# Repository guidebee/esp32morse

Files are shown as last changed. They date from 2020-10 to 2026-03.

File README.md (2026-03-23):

# Morse Code LoRa Walkie-Talkie

Morse Code Walkie Talkie

A battery-powered Morse code walkie-talkie built on the **TTGO LoRa32 v1** (ESP32). Type messages in Morse code using a physical key, transmit over LoRa radio, and receive messages on an OLED display — with multi-device support, AES encryption, and configurable channels.

[Watch Demo on YouTube](https://www.youtube.com/watch?v=TG7tIteto1E)

---

## Hardware

- **Board**: TTGO LoRa32 v1 (ESP32 + SX127x LoRa + SSD1306 OLED)
- **Framework**: PlatformIO / Arduino (C++)
- **Pins**:
  - `GPIO 35` — Battery level ADC
  - `GPIO 33` — Power switch
  - `GPIO 12` — Receiver LED
  - `GPIO 13` — Bluetooth LED

---

## Features

- **Morse code input** via physical key — short press = dit (`.`), long press = dah (`-`)
- **LoRa radio** for long-range communication (up to several kilometers)
- **OLED display** split into: scrolling top screen (received messages), bottom screen (composing), top bar (uptime/title), status bar (device/signal info + battery indicator)
- **Device discovery** — auto-tracks nearby nodes by chip ID and assigns short indexes
- **AES encryption** for secure message transmission
- **Multi-channel support** — configurable channel ID and LoRa sync word
- **Buzzer feedback** — audible dit/dah tones, message sent/received sounds, error beeps
- **BLE toggle** — optional Bluetooth support
- **Battery level indicator** in the status bar corner
- **Deep sleep support** (optional, disabled by default)

---

## Controls

| Button | Action |
|---|---|
| **Main** (short press) | Dit (`.`) |
| **Main** (long press) | Dah (`-`) |
| **Left** | Backspace (delete last character) |
| **Right** | Insert space |
| **OK** | Send message (if composing), or enter Options menu (press 3× when idle) |

Max message length is 36 characters — long messages are auto-sent when the limit is reached.

---

## Options Menu

Press **OK** three times while idle to enter the settings menu. Navigate with Left/Right, confirm with OK.

| Option | Description |
|---|---|
| Device Name | Set a display name for this node |
| Play Sound | Toggle buzzer feedback on/off |
| Bluetooth | Enable/disable BLE |
| Channel Id | Set the channel number (numeric) |
| Sync Word | Set the LoRa sync word (0x00–0xFF) |
| Input Speed | Normal (150 ms threshold) or Fast (100 ms) |
| Exit | Return to main screen |

Settings are persisted to flash via the `Preferences` library.

---

## Build & Flash

### Requirements

- [PlatformIO](https://platformio.org/) (VS Code extension or CLI)

### Libraries (auto-installed via `platformio.ini`)

- `adafruit/Adafruit BusIO`
- `thijse/ArduinoLog`
- `arduinogetstarted/ezButton`
- `sandeepmistry/LoRa`
- `adafruit/Adafruit GFX Library`
- `adafruit/Adafruit SSD1306`

### Flash

Select the environment matching your OS:

```bash
# macOS
pio run -e ttgo-lora32-v1-mac -t upload

# Windows (default COM3)
pio run -e ttgo-lora32-v1-windows -t upload

# Linux
pio run -e ttgo-lora32-v1-unix -t upload
```

Adjust the `upload_port` in `platformio.ini` if your serial port differs.

---

## Message Protocol

Each LoRa packet includes the sender's chip ID and a message type:

| Type | Description |
|---|---|
| `HELLO` | Broadcast on startup; announces device name and enables discovery |
| `TEXT` | A Morse-decoded text message |
| `TEXT_ACK` | Acknowledgment of a received text message |

Received messages are displayed as `<index>:<device_name> <text>` in the top screen.

---

## Photos

| | |
|---|---|
|  |  |
|  |  |

---

## License

MIT

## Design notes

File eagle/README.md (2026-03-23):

# ESP32 Morse LoRa - PCB Design (Eagle)

PCB design for the LoRa Morse code walkie-talkie, designed in Autodesk EAGLE 9.6.2.

## Files

| File | Description |
|---|---|
| `morse_lora_v6.sch` | Latest schematic |
| `morse_lora_v6.brd` | Latest board layout |
| `morse_lora_v1–v5.*` | Prior revision history |

## Board Specs

- **Size**: ~55mm × 83mm (2.2" × 3.3")
- **Layers**: 2 (Top + Bottom)
- **Components**: 29 (through-hole / PTH)
- **Software**: EAGLE 9.6.2

## Bill of Materials (v6)

| Ref | Qty | Value | Description |
|-----|-----|---|---|
| ESP32LORA | 1 | — | TTGO WiFi-LoRa-32 v1 module |
| C1–C4 | 4 | 0.1µF 50V | Decoupling capacitors |
| R1–R6 | 6 | 10kΩ 1/4W | Button pull-up/pull-down resistors |
| R7–R9 | 3 | 330Ω 1/10W | LED current limiting resistors |
| D-REC | 1 | Red 5mm LED | Receive indicator |
| D-BUT | 1 | Red 5mm LED | Button press feedback |
| D-BLU | 1 | Blue 5mm LED | Radio/BT status |
| RIGHT, LEFT, OK | 3 | 6mm switch | Navigation buttons (momentary PTH) |
| MAIN | 1 | 12mm switch | Main/power button (momentary PTH) |
| SLEEP | 1 | EG1218 | Sleep mode toggle switch |
| BUZZER | 1 | — | PTH electromechanical buzzer |

## Viewing the Files

Since EAGLE `.brd`/`.sch` files are XML-based, you can view them with:

- **[Autodesk EAGLE](https://www.autodesk.com/products/eagle/)** (free tier available) — full editing
- **[KiCad](https://www.kicad.org/)** with the EAGLE import plugin — open source
- **[EasyEDA](https://easyeda.com/)** — browser-based, supports EAGLE import
- **[Gerber viewers](https://www.pcbway.com/project/OnlineGerberViewer.html)** — after exporting Gerbers from EAGLE

## Design Revision History

| Version | Notes |
|---|---|
| v1 | Initial design — PTH switches, 5mm LEDs, discrete passives |
| v2 | Minor iteration on v1 |
| v3 | SMD redesign (0603 resistors, 1206 LEDs, SMD buzzer) — later reverted |
| v4 | Reverted to PTH; added SLEEP switch |
| v5 | Minor iteration on v4 |
| v6 | Added 330Ω LED current-limiting resistors (R7–R9); upgraded MAIN to 12mm switch |

The v3 SMD attempt was reverted in v4, settling on a PTH-first approach for easier hand-assembly and mechanical reliability of the buttons/switches.

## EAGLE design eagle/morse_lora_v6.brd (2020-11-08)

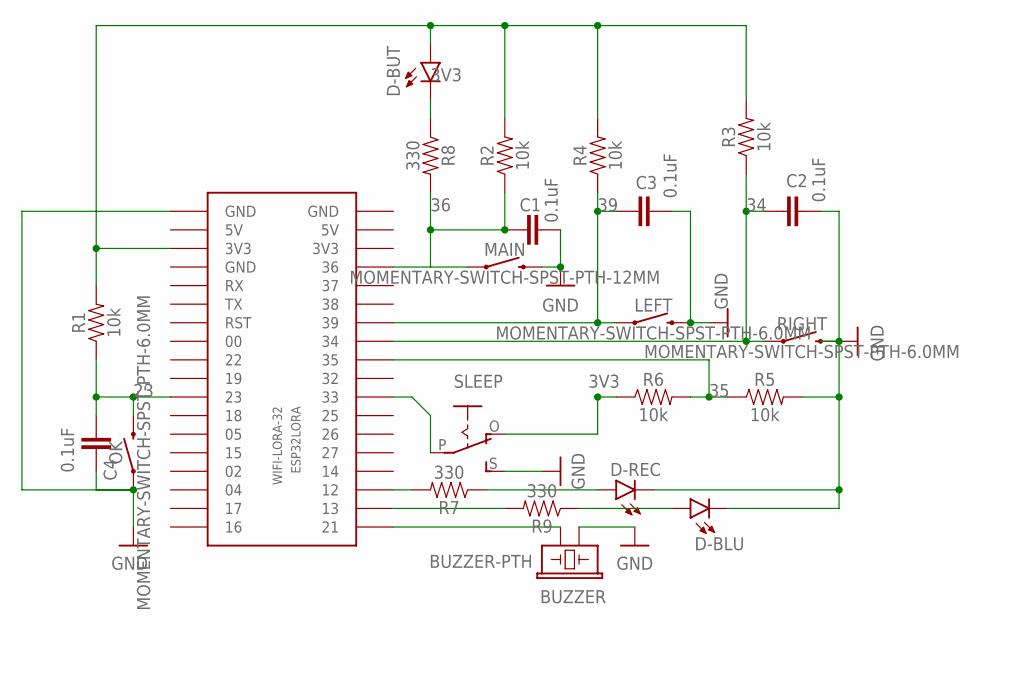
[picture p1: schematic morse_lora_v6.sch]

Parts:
BUZZER: BUZZER-PTH; BUZZER-12MM
C1, C2, C3, C4: 0.1uF; CAP-PTH-SMALL-KIT
D-BLU: LED5MM; LED_5MM
D-BUT: LED5MM; LED_5MM
D-REC: LED5MM; LED_5MM
ESP32LORA: WIFI-LORA-32; 2.54MM_2X18
LEFT: MOMENTARY-SWITCH-SPST-PTH-6.0MM; TACTILE_SWITCH_PTH_6.0MM
MAIN: MOMENTARY-SWITCH-SPST-PTH-12MM; TACTILE_SWITCH_PTH_12MM
OK: MOMENTARY-SWITCH-SPST-PTH-6.0MM; TACTILE_SWITCH_PTH_6.0MM
R1, R2, R3, R4, R5, R6: 10k; AXIAL-0.3-KIT
R7, R8, R9: 330; AXIAL-0.3
RIGHT: MOMENTARY-SWITCH-SPST-PTH-6.0MM; TACTILE_SWITCH_PTH_6.0MM
SLEEP: EG1218S; EG1218

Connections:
3V3: D-BUT.A, ESP32LORA.P$3 (3V3), R1.P$2 (2), R2.P$2 (2), R3.P$2 (2), R4.P$2 (2), R6.P$1 (1), SLEEP.O
23: C4.2, ESP32LORA.P$11 (23), OK.3 (2), R1.P$1 (1)
34: C2.2, ESP32LORA.P$29 (34), R3.P$1 (1), RIGHT.1
35: ESP32LORA.P$28 (35), R5.P$1 (1), R6.P$2 (2)
36: C1.2, ESP32LORA.P$33 (36), MAIN.1, R2.P$1 (1), R8.P$2 (2)
39: C3.1, ESP32LORA.P$30 (39), LEFT.1, R4.P$1 (1)
GND: BUZZER.- (2), C1.1, C2.1, C3.2, C4.1, D-BLU.K (C), D-REC.K (C), ESP32LORA.P$1 (GND), LEFT.3 (2), MAIN.3 (2), OK.1, R5.P$2 (2), RIGHT.3 (2), SLEEP.S
unnamed: ESP32LORA.P$21 (12), R7.P$2 (2)
unnamed: D-BUT.K (C), R8.P$1 (1)
unnamed: D-BLU.A, R9.P$1 (1)
unnamed: BUZZER.+ (1), ESP32LORA.P$19 (21)
unnamed: D-REC.A, R7.P$1 (1)
unnamed: ESP32LORA.P$20 (13), R9.P$2 (2)
unnamed: ESP32LORA.P$26 (33), SLEEP.P

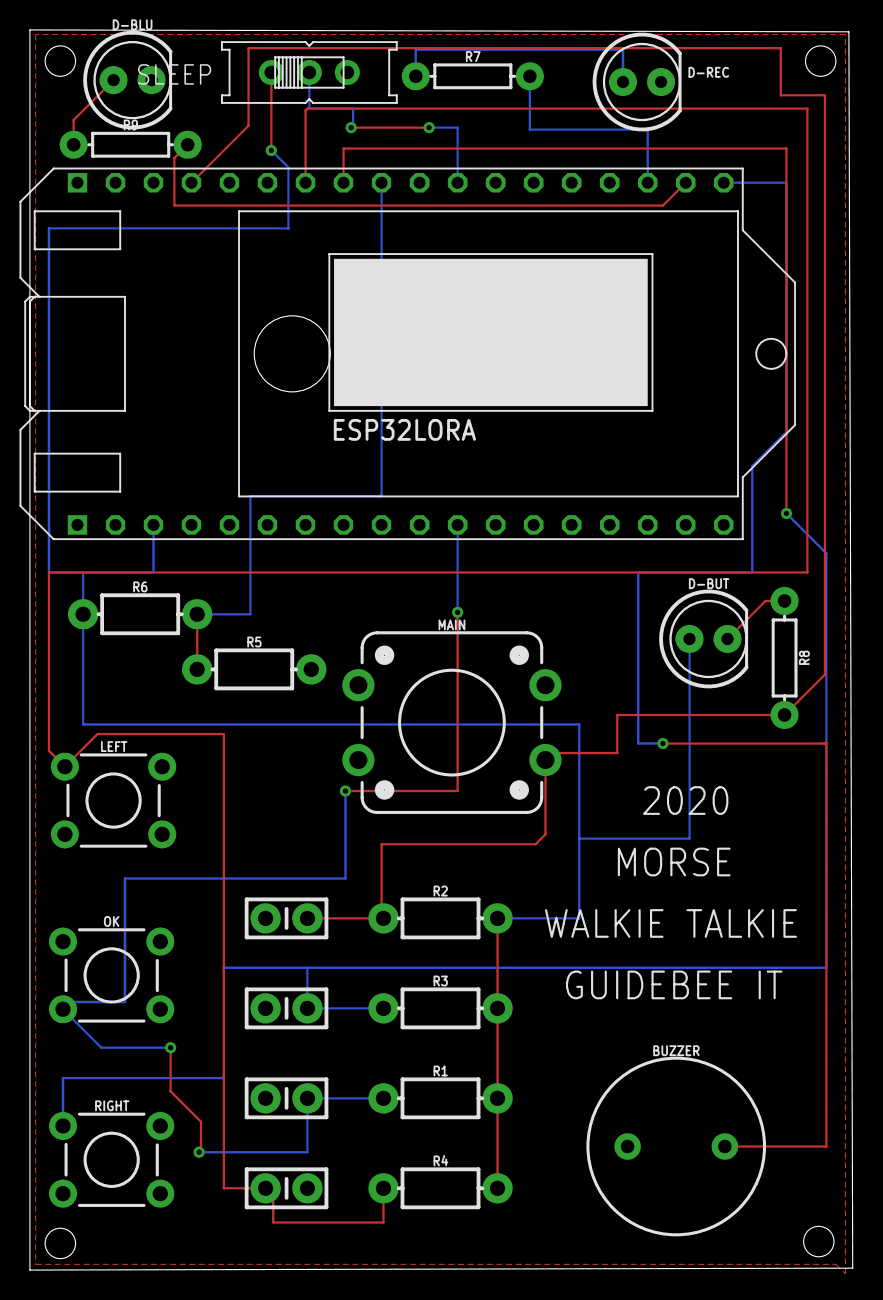
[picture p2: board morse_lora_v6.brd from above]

Board: 2 copper layers, 55.0 x 82.9 mm, 23 parts (0 on the bottom side), 14 nets.

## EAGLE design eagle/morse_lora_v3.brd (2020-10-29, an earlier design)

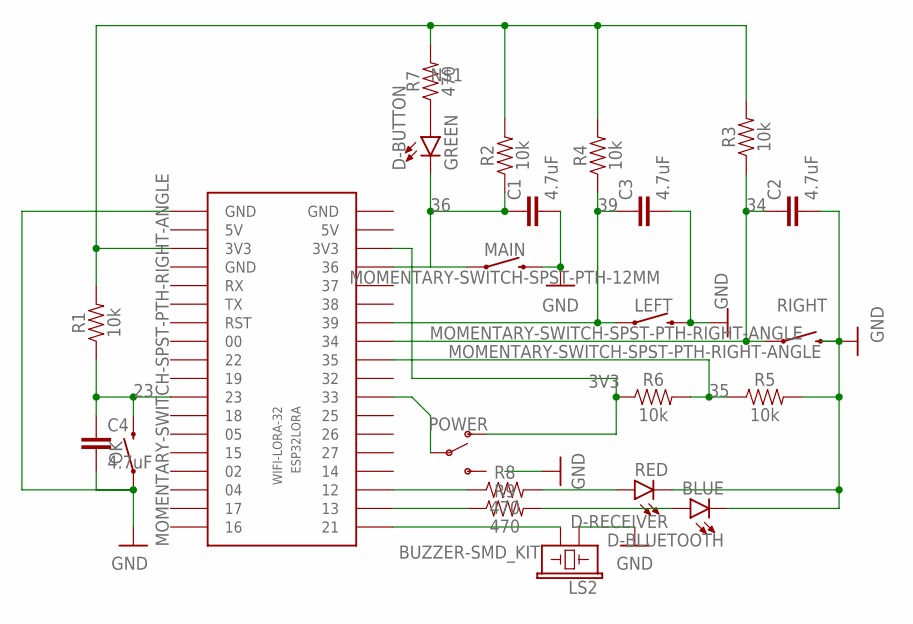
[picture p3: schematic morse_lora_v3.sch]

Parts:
C1, C2, C3, C4: 4.7uF; 0603
D-BLUETOOTH: BLUE; LED-1206
D-BUTTON: GREEN; LED-1206
D-RECEIVER: RED; LED-1206
ESP32LORA: WIFI-LORA-32; 2.54MM_2X18
LEFT: MOMENTARY-SWITCH-SPST-PTH-RIGHT-ANGLE; TACTILE_SWITCH_PTH_RIGHT_ANGLE
LS2: BUZZER-SMD_KIT; BUZZER-CCV-KIT
MAIN: MOMENTARY-SWITCH-SPST-PTH-12MM; TACTILE_SWITCH_PTH_12MM
OK: MOMENTARY-SWITCH-SPST-PTH-RIGHT-ANGLE; TACTILE_SWITCH_PTH_RIGHT_ANGLE
POWER: SWITCH-SPDT-SMD-RIGHT-ANGLE; SWITCH_SPST_SMD_A
R1, R2, R3, R4, R5, R6: 10k; 0603
R7, R8, R9: 470; 0603
RIGHT: MOMENTARY-SWITCH-SPST-PTH-RIGHT-ANGLE; TACTILE_SWITCH_PTH_RIGHT_ANGLE

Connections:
3V3: ESP32LORA.P$3 (3V3), ESP32LORA.P$34 (3V3), POWER.1 (O), R1.2, R2.2, R3.2, R4.2, R6.1, R7.2
23: C4.1, ESP32LORA.P$11 (23), OK.2, R1.1
34: C2.1, ESP32LORA.P$29 (34), R3.1, RIGHT.1
35: ESP32LORA.P$28 (35), R5.1, R6.2
36: C1.1, D-BUTTON.C, ESP32LORA.P$33 (36), MAIN.1, R2.1
39: C3.1, ESP32LORA.P$30 (39), LEFT.1, R4.1
GND: C1.2, C2.2, C3.2, C4.2, D-BLUETOOTH.C, D-RECEIVER.C, ESP32LORA.P$1 (GND), LEFT.2, LS2.+ (1), MAIN.3 (2), OK.1, R5.2, RIGHT.2
unnamed: D-BUTTON.A, R7.1
unnamed: D-RECEIVER.A, R8.2
unnamed: ESP32LORA.P$20 (13), R9.1
unnamed: ESP32LORA.P$19 (21), LS2.- (2)
unnamed: ESP32LORA.P$21 (12), R8.1
unnamed: D-BLUETOOTH.A, R9.2
unnamed: ESP32LORA.P$26 (33), POWER.2

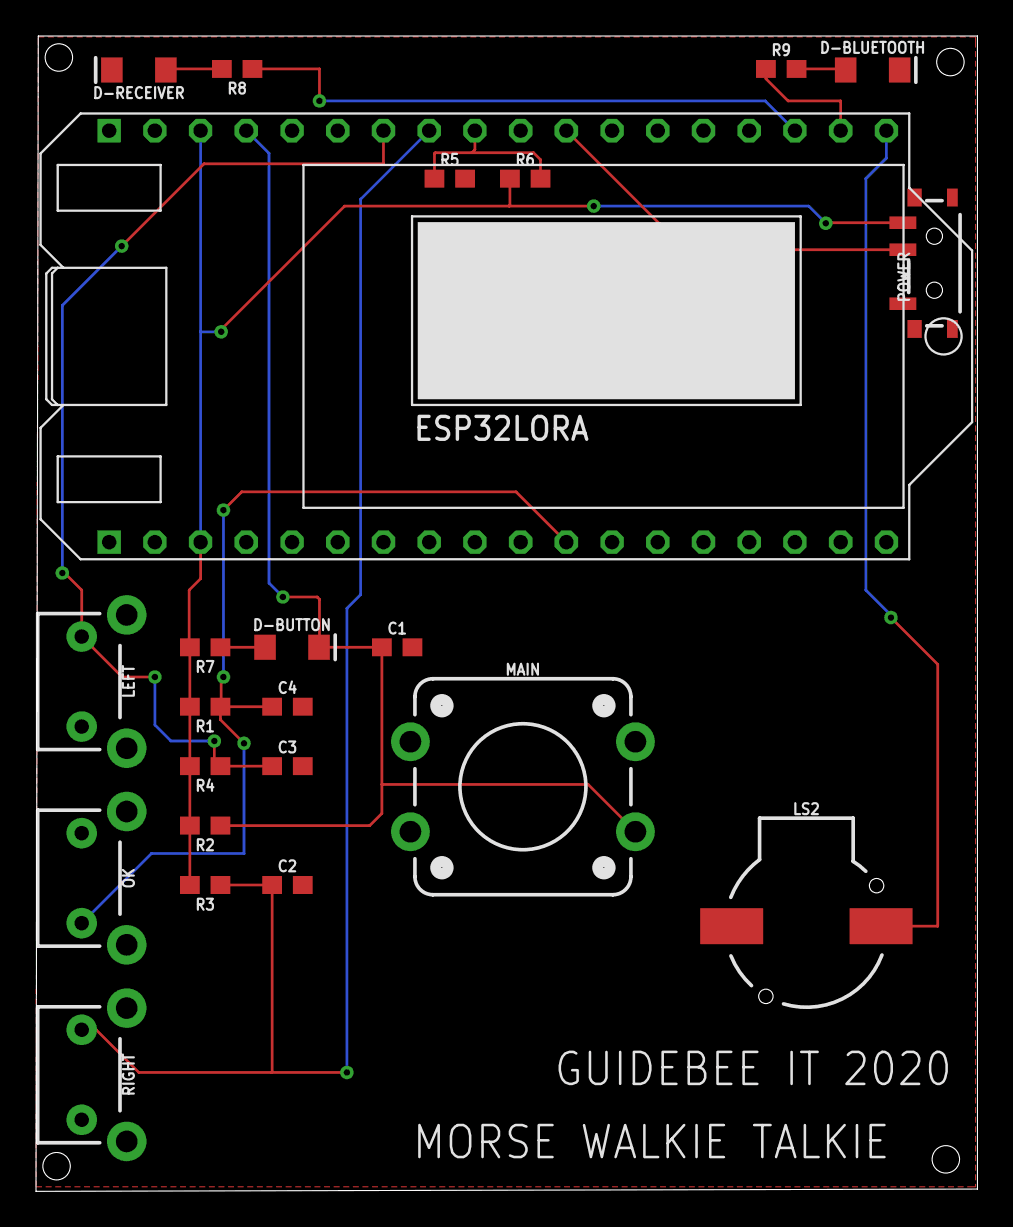
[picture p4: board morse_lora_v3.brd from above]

Board: 2 copper layers, 52.3 x 64.2 mm, 23 parts (0 on the bottom side), 14 nets.

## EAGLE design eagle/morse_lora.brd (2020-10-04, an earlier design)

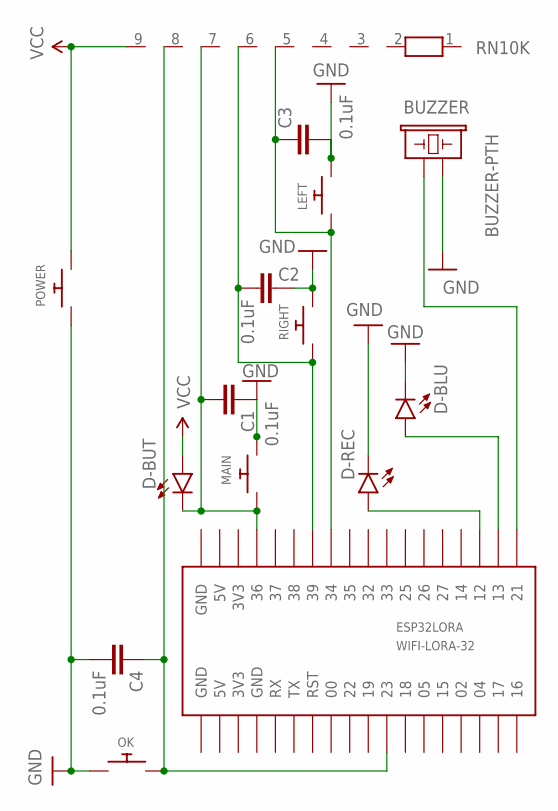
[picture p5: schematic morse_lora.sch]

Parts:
BUZZER: BUZZER-PTH; BUZZER-12MM
C1, C2, C3, C4: 0.1uF; CAP-PTH-SMALL-KIT
D-BLU: LED5MM; LED_5MM
D-BUT: LED5MM; LED_5MM
D-REC: LED5MM; LED_5MM
ESP32LORA: WIFI-LORA-32; 2.54MM_2X18
LEFT: SWITCH_PUSHBUTTONEVQ-PE; TACT_PANA-EVQ
MAIN: SWITCH_PUSHBUTTONEVQ-PE; TACT_PANA-EVQ
OK: SWITCH_PUSHBUTTONEVQ-PE; TACT_PANA-EVQ
POWER: SWITCH_PUSHBUTTONEVQ-PE; TACT_PANA-EVQ
RIGHT: SWITCH_PUSHBUTTONEVQ-PE; TACT_PANA-EVQ
RN10K: RN08; RN-9

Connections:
GND: BUZZER.- (2), C1.1, C2.1, C3.2, C4.2, D-BLU.K (C), D-REC.K (C), LEFT.P$2, MAIN.P$2, OK.P$1, POWER.P$1, RIGHT.P$2
unnamed: C1.2, D-BUT.K (C), ESP32LORA.P$33 (36), MAIN.P$1, RN10K.7
unnamed: C2.2, ESP32LORA.P$30 (39), RIGHT.P$1, RN10K.6
unnamed: C3.1, ESP32LORA.P$29 (34), LEFT.P$1, RN10K.5
unnamed: BUZZER.+ (1), ESP32LORA.P$19 (21)
unnamed: D-REC.A, ESP32LORA.P$21 (12)
unnamed: D-BLU.A, ESP32LORA.P$20 (13)
unnamed: C4.1, ESP32LORA.P$11 (23), OK.P$2, RN10K.8
VCC: D-BUT.A, POWER.P$2, RN10K.9

Board: 2 copper layers, 15 parts (0 on the bottom side), 9 nets, no tracks yet.

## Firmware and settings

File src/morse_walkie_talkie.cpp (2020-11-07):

//
// Created by Jing SHEN on 27/9/20.
//
#include <string>
#include "morse_walkie_talkie.hpp"
#include <soc/efuse_reg.h>
#include "configuration.hpp"

#define BATTERY_LEVEL_PIN 35
#define MAX_MESSAGE_LENGTH 36
#define POWER_SWITCH_PIN 33
#define BUTTON_PIN_BITMASK 0x200000000 // 2^33 in hex

bool isOptionMode = false;
Configuration globalConfiguration;
union {
    uint32_t parts[4];
    unsigned char bytes[16];
} encryptedChipId;

void MorseWalkieTalkie::sendMessage(char character) {
    if (!message.empty()) {
        lastChar = ' ';
        loRaRadio.sendMessage(message);
        bottomScreen.print(character);
        auto morseText = morseCode.generateDitDashString(message);
        Serial.print(morseText.c_str());
        if (globalConfiguration.playSound) {
            buzzer.playMessageSent();
        }
        receiverLed.signalMessageSent();
        message = "";
    }
}


void MorseWalkieTalkie::deleteLastKey() {
    bool deleted = bottomScreen.backspace();
    if (deleted) {
        message = message.substr(0, message.length() - 1);
    }
}


void MorseWalkieTalkie::onEmit(char character, std::string raw) {

    switch (character) {
        case '*':
            deleteLastKey();
            break;
        case '^':
            if (globalConfiguration.playSound) {
                buzzer.playError();
            }
            receiverLed.signalError();
            break;
        default:
            if (!(character == ' ' and lastChar == ' ')) {
                if (character != '\n') {
                    message += character;
                    bottomScreen.print(character);
                    receiverLed.signalMorse(raw);
                }
            }
            lastChar = character;
            if (character == '\n') {
                sendMessage(character);
            }
            if (message.length() >= MAX_MESSAGE_LENGTH) {
                sendMessage('-');
            }
            break;
    }

}

void MorseWalkieTalkie::onCharStart() {

}

void MorseWalkieTalkie::onCharEnd(char dotOrDash, int length) {
    if (globalConfiguration.playSound) {
        if (dotOrDash == '.') {
            buzzer.playDi();
        } else if (dotOrDash == '-') {
            buzzer.playDah();
        }
    }
}


void MorseWalkieTalkie::onMainPressed() {
    last_mills = millis();

    isDown = true;

    morseCode.setOnOff(true);
}


void MorseWalkieTalkie::saveConfiguration() {
    preferences.begin("guidebeeit", false);
    preferences.putString("deviceName", "Harry");
    preferences.putString("channelId", "<1234>");
    preferences.putBool("inputSpeed", false);
    preferences.putUChar("syncWord", 0x34);
    preferences.putBool("playSound", true);
    preferences.end();
}


void MorseWalkieTalkie::readConfiguration() {
    uint64_t chipId = ESP.getEfuseMac();//The chip ID is essentially its MAC address(length: 6 bytes).
    char buffer[64];
    sprintf(buffer, "%08X", (uint16_t) (chipId >> 32));//print High 2 bytes
    globalConfiguration.chipId = buffer;
    sprintf(buffer, "%08X", (uint32_t) chipId);//print Low 4bytes.
    globalConfiguration.chipId += buffer;
    //saveConfiguration();
    preferences.begin("guidebeeit", false);
    globalConfiguration.deviceName = preferences.getString("deviceName", "Morse").c_str();
    globalConfiguration.playSound = preferences.getBool("playSound", true);
    globalConfiguration.inputSpeed = preferences.getBool("inputSpeed", false);
    globalConfiguration.bluetooth = preferences.getBool("bluetooth", false);
    globalConfiguration.channelIdValue = preferences.getInt("channelIdValue", 1234);
    globalConfiguration.channelId = preferences.getString("channelId", "<1234>").c_str();
    globalConfiguration.syncWord = preferences.getUChar("syncWord", 0x34);
    preferences.end();
    Serial.printf("%s\n", globalConfiguration.deviceName.c_str());
    if (globalConfiguration.inputSpeed) {
        keyInterval = 100;
    } else {
        keyInterval = 150;
    }
    sprintf(globalConfiguration.encryptionKey, "guidebeeit202010");
    printf("Chip Id=%s\n", globalConfiguration.chipId.c_str());
}

void MorseWalkieTalkie::setup() {
// write your initialization code here

    esp_chip_info_t chip_info;
    esp_chip_info(&chip_info);
    printf("This is %s chip with %d CPU cores, WiFi%s%s, ",
           "esp32",
           chip_info.cores,
           (chip_info.features & CHIP_FEATURE_BT) ? "/BT" : "",
           (chip_info.features & CHIP_FEATURE_BLE) ? "/BLE" : "");

    printf("silicon revision %d, ", chip_info.revision);

    printf("%dMB %s flash\n", spi_flash_get_chip_size() / (1024 * 1024),
           (chip_info.features & CHIP_FEATURE_EMB_FLASH) ? "embedded" : "external");

    printf("Minimum free heap size: %d bytes\n", esp_get_minimum_free_heap_size());
    Serial.begin(115200);

    while (!Serial && !Serial.available()) {}
    randomSeed(analogRead(0));
    pinMode(POWER_SWITCH_PIN, INPUT_PULLDOWN);
    esp_sleep_enable_ext1_wakeup(BUTTON_PIN_BITMASK, ESP_EXT1_WAKEUP_ANY_HIGH);
    Log.begin(LOG_LEVEL_VERBOSE, &Serial);
    Serial.print("Enter deep sleep");

    if (supportSleep) {
        int value = digitalRead(POWER_SWITCH_PIN);
        if (value == HIGH) {
            // Serial.print("High\n");
        } else {
            // Serial.print("Low\n");
            esp_deep_sleep_start();
        }
    }
    readConfiguration();
    display.setup();
    topScreen.clearScreen();
    bottomScreen.clearScreen();
    topBar.clearScreen();
    topBar.addDrawListener(this);
    statusBar.clearScreen();
    buzzer.setup();
    receiverLed.setup();
    blueToothLed.setup();

    std::string app_name = "hi";
    auto morseText = morseCode.generateDitDashString(app_name);
    receiverLed.signalMorseText(morseText);
    blueToothLed.signalMorseText(morseText);
    keypad.setup();
    morseCode.addListener(this);
    keypad.addListener(this);

    char letter = morseCode.getMorseLetter("...");
    Serial.println(letter);
    last_mills = millis();
    start_mills = last_mills;
    current_mills = last_mills;
    last_task_mills = last_mills;
    last_top_bar_mills = last_mills;
    diff_mills = 0;
    samplePeriod = morseCode.getSamplePeriod();
    pinMode(BATTERY_LEVEL_PIN, INPUT);
    optionMenu.setup();

    if (needCheckDevice) {
        bool isValid = isValidDevice();
        if (!isValid) {
            topScreen.print("Not a valid device\nReboot in 5s\n");
            statusBar.displayText("Copyright Guidebee IT\n", statusBarPattern, true);
            delay(5000);
            esp_deep_sleep_start();
        } else {
            Serial.printf("Device validation Ok\n");
        }
    }

}
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

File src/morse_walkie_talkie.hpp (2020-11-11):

//
// Created by Jing SHEN on 27/9/20.
//

#ifndef ESP32MORSE_MORSE_WALKIE_TALKIE_HPP
#define ESP32MORSE_MORSE_WALKIE_TALKIE_HPP

#include <Arduino.h>
#include <ArduinoLog.h>
#include <map>
#include <Preferences.h>
#include "morse_code.hpp"
#include "oled_display.hpp"
#include "screen.hpp"
#include "lora_radio.hpp"
#include "buzzer_tone.hpp"
#include "signal_led.hpp"
#include "keypad.hpp"
#include "option_menu.hpp"

#include "freertos/task.h"
#include "esp_system.h"
#include "esp_spi_flash.h"


#define RECEIVER_LED 12
#define BLUETOOTH_LED 13

#define ENTER_MENU_COUNT 3

const bool startLow = true;
const bool supportSleep = false;
const bool needCheckDevice = false;

struct UserInfo {
    int index;
    std::string deviceName;
    int counter;
};


class MorseWalkieTalkie : public MorseCodeListener,
                          public KeypadListener,
                          public LoraMessageListener,
                          public ExtraDisplayListener {
private:
    unsigned long last_mills;
    unsigned long current_mills;

    unsigned long last_top_bar_mills;
    bool showLogo = false;

    unsigned long last_task_mills;
    unsigned long diff_mills;
    OledDisplay display;
    SignalLed receiverLed;
    SignalLed blueToothLed;
    DynamicScreen topBar;
    Screen topScreen;
    Screen bottomScreen;
    DynamicScreen statusBar;
    BuzzerTone buzzer;
    LoraRadioClass loRaRadio;
    KeyboardMorseCodeDecoder morseCode;
    Keypad keypad;
    int enterMenuCounter = 0;
    int keyInterval = 150;

    bool isDown = true;
    std::string message;
    char lastChar = '^';
    int samplePeriod;

    int userIndex = 0;
    Preferences preferences;
    std::map<std::string, UserInfo> users;
    std::list<int> topBarPattern = std::list<int>{9500, 500};
    std::list<int> statusBarPattern = std::list<int>{300, 200, 300, 200, 500, 10};

    OptionMenu optionMenu;
    int lastBatteryLevel = -1;


    bool initialGreeting = false;
    unsigned long start_mills = 0;

public:
    explicit MorseWalkieTalkie() : receiverLed(SignalLed(RECEIVER_LED, startLow)),
                                   blueToothLed(SignalLed(BLUETOOTH_LED, startLow)),
                                   topBar(DynamicScreen(&display, 0, 1, true)),
                                   topScreen(Screen(&display, 1, 5, false, false, 0)),
                                   bottomScreen(Screen(&display, 5, 7, true, true)),
                                   statusBar(DynamicScreen(&display, 7, 8, false)) {}

    void setup();

    void loop();

    void onEmit(char character, std::string raw) override;

    void onCharStart() override;

    void onCharEnd(char dotOrDash, int length) override;

    void onMainPressed() override;

    void onMainReleased() override;

    void onLeftPressed() override;

    void onLeftReleased() override;

    void onRightPressed() override;

    void onRightReleased() override;

    void onOkPressed() override;

    void onOkReleased() override;

    void onMessageReceived(LoraMessage message) override;

    void drawExtra() override;

private:
    void sendMessage(char character);

    void deleteLastKey();

    void readConfiguration();

    void drawBatterLevel();

    void saveConfiguration();

    UserInfo addUser(std::string chipId, std::string deviceName);

    UserInfo getUser(std::string chipId);

    void updateUserCounter(std::string chipId, int counter);

    bool isValidDevice();

};

#endif //ESP32MORSE_MORSE_WALKIE_TALKIE_HPP

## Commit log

2020-08-23 start the project esp32 morse code walkie talkie
2020-09-26 remove delay and add led and audio class
2020-09-27 add bluetooth led
2020-09-30 add default device name
2020-10-02 save device name, sync word and channel id
2020-10-03 add schmetic
    [morse_lora.sch]
2020-10-04 add power switch
2020-10-04 add power icon
    [morse_lora_v1.sch]
2020-10-04 draw battery level
2020-10-04 rotate schematic
    [morse_lora_v1.sch]
2020-10-05 draft layout
    [morse_lora_v1.brd, morse_lora_v1.sch]
2020-10-06 revert back to broken change (no message received)
    [morse_walkie_talkie.cpp, morse_walkie_talkie.hpp]
2020-10-06 add back device checking
2020-10-17 add pcb v2
    [morse_lora_v2.brd, morse_lora_v2.sch]
2020-10-17 update pcb v1
    [morse_lora_v1.brd, morse_lora_v1.sch]
2020-10-23 update pcb v2
    [morse_lora_v1.brd, morse_lora_v2.brd]
2020-10-29 board v3 and v4
    [morse_lora_v3.brd, morse_lora_v3.sch, morse_lora_v4.brd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]
2020-10-31 board v5
    [morse_lora_v5.brd, morse_lora_v5.sch]
2020-10-31 draw battery level more often
2020-11-05 rough battery level
2020-11-08 v6 board
    [morse_lora_v6.brd, morse_lora_v6.sch]
2020-11-11 option to swap led
    [morse_walkie_talkie.hpp]

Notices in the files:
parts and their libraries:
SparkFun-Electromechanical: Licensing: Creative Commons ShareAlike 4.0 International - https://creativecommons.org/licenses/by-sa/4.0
